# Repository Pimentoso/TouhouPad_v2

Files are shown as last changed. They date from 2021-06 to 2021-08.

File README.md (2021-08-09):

WARNING: THIS REPO IS STILL A WORK IN PROGRESS

Ergonomic gamepad to play Touhou Project games. Left-hand controls shoot/slow/bomb, and right hand controls movement. The bomb button is supposed to be pressed with the left thumb.

This is a newer version which uses a proper circuit board; for the old hand-wired version check here -> https://github.com/Pimentoso/TouhouPad

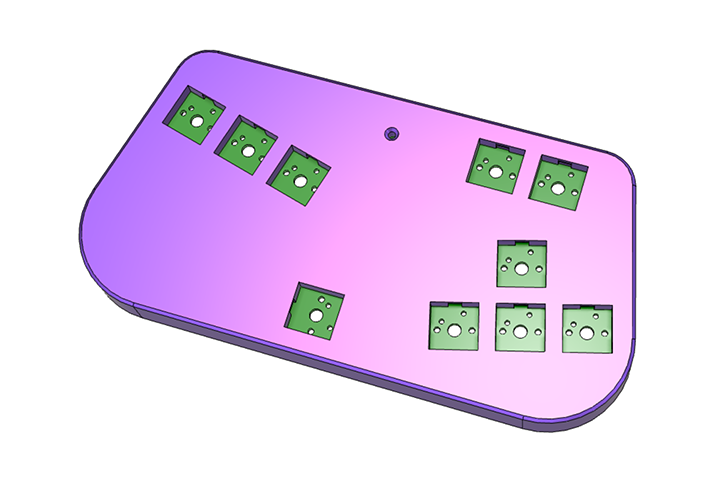
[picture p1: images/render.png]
Rendering


## Ordering the circuit board

- Go to https://jlcpcb.com/
- Create an account if needed.
- Click "order now"
- Upload the file `Archive.zip` you can find in the `kicad/gerber/` directory.
- Leave everything at default (you can change the pcb color if yolu want) and place the order. Note the minimum quantity you can order is 5

## Printing the enclosure

- You will need to 3d print the enclosure for the pad. You can find it in the `stl/` directory
- Print it face down without supports.
- In the top center of the plate there is a small hole. After you finish building the pad, you can stick a very small piece of transparent filament inside the hole to make the arduino power light shine through better.

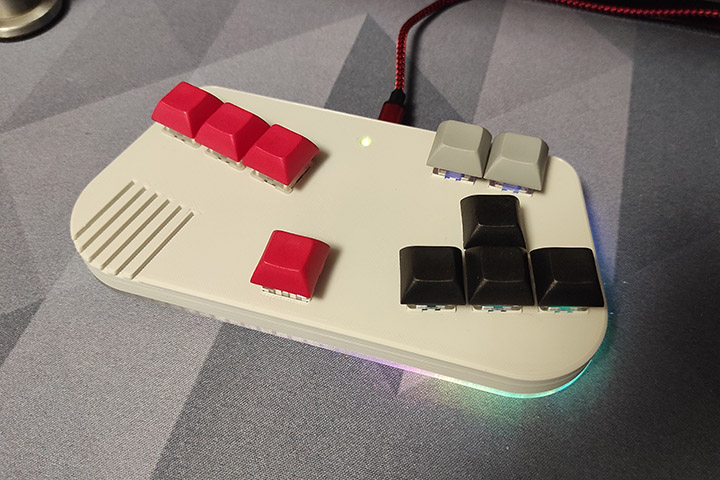
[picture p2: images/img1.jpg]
Top


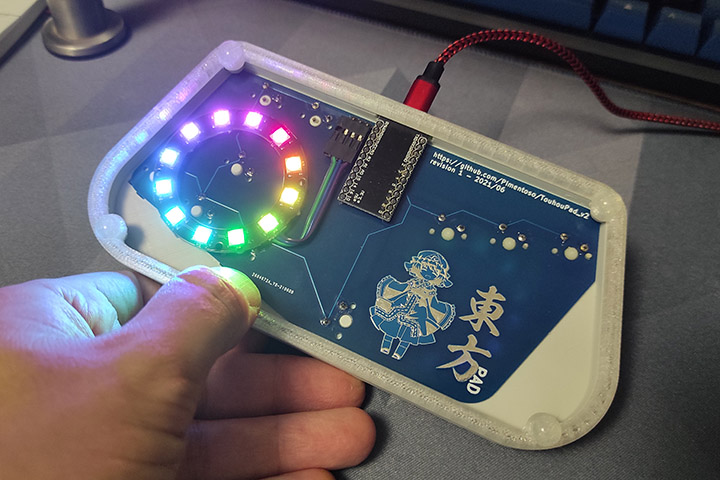
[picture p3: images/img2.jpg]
Bottom


(the circuit board in the picture is the prototype version)

## Building the pad

You will need
- Touhoupad circuit board (see above)
- 3d-printed enclosure
- Arduino pro micro board -> https://www.aliexpress.com/item/32888212119.html (the black one)
- 10x mx-style switches -> https://www.aliexpress.com/item/32899833333.html (gateron red or yellow are good for gaming)
- 10x keycaps -> https://www.aliexpress.com/item/32842379355.html (or just scavenge from an old mechanical keyboard)
- (optional) 4 silicone adhesive dots/feet
- (optional) a short RGB strip (ws2812b LEDs)

Solder the arduino to the circuit board. Place the circuit board inside the case, snap the switches in and solder them.

For RGB underglow: you can use the 3 exposed pins on the circuit board to solder a RGB strip. You can control the RGB lighting as follows

- Press esc+left arrow: toggle lighting on/off
- Press esc+right arrow: cycle lighting effects
- Press esc+up/down arrow: raise/lower brightness

Works better if you print the bottom part of the enclosure with transparent filament. Just pause the print at the 11mm mark and switch the filament to transparent.

## Flashing the firmware

- Method 1: flash `firmware/pimentoso_touhoupad_default.hex` using QMK Toolbox.
- Method 2: flash it directly using qmk firmware: `make pimentoso/touhoupad:default:flash`
- To enter bootloader mode: the bottom of the pad is completely exposed so you have access to the Arduino Pro micro. Just short together the RST and GND pins using a metal object to access bootloader mode.

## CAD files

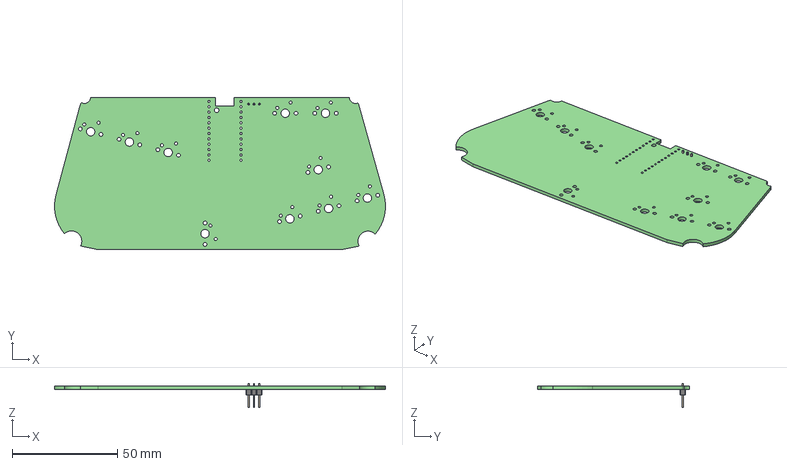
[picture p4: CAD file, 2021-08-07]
step/pcb.step
157.1 x 72.2 x 11.5 mm

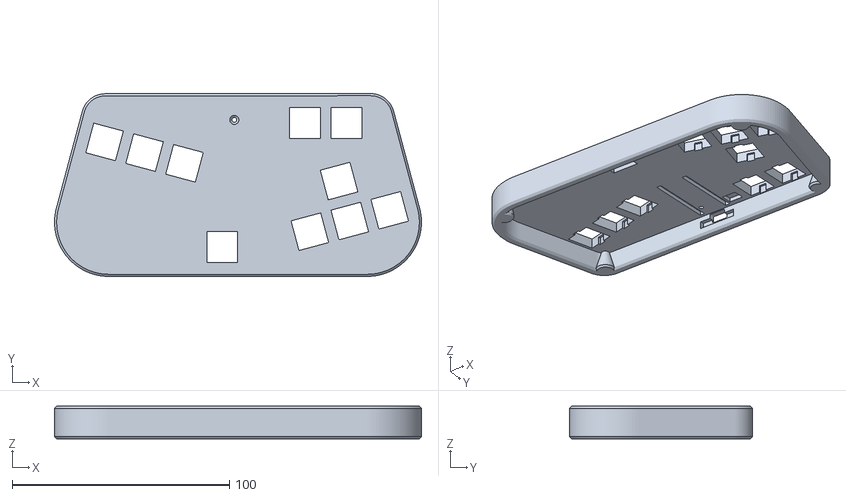
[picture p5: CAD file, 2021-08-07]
stl/touhoupad.stl
169.1 x 84.2 x 15.0

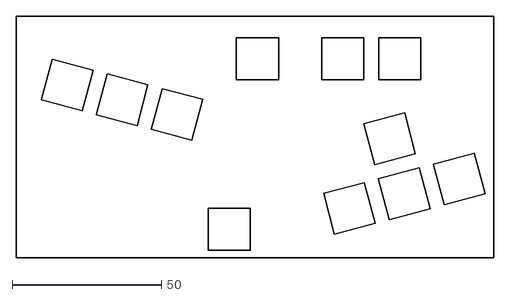
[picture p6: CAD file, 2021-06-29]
dxf/d0646518d6474f0d7bef433ed9ec5677a3568018_switch.dxf
160.0 x 80.8

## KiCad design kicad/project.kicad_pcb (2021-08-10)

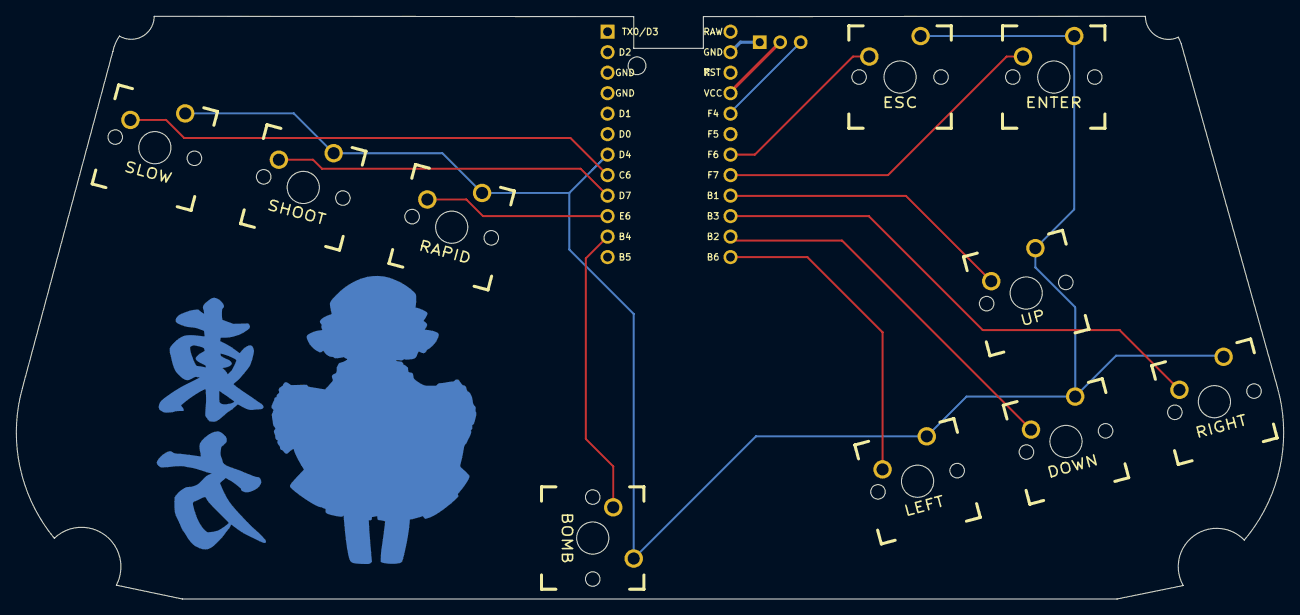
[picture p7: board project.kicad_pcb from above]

Board: 2 copper layers, 157.1 x 72.2 mm, 12 parts (1 on the bottom side), 14 nets.

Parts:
BOMB: SW_DIP_x01; MX_PCB_100H
DOWN: SW_DIP_x01; MX_PCB_100H
ENTER: SW_DIP_x01; MX_PCB_100H
ESC: SW_DIP_x01; MX_PCB_100H
J0: Conn_01x03_Female; PinHeader_1x03_P2.54mm_Vertical
LEFT: SW_DIP_x01; MX_PCB_100H
RAPID: SW_DIP_x01; MX_PCB_100H
RIGHT: SW_DIP_x01; MX_PCB_100H
SHOOT: SW_DIP_x01; MX_PCB_100H
SLOW: SW_DIP_x01; MX_PCB_100H
U0: ProMicro here!; ArduinoProMicro
UP: SW_DIP_x01; MX_PCB_100H

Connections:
unnamed: J0.1, U0.23
unnamed: J0.2, U0.21
unnamed: J0.3, U0.20
unnamed: BOMB.1, DOWN.1, ENTER.1, ESC.1, LEFT.1, RAPID.1, RIGHT.1, SHOOT.1, SLOW.1, U0.7, UP.1
unnamed: SLOW.2, U0.8
unnamed: SHOOT.2, U0.9
unnamed: RAPID.2, U0.10
unnamed: BOMB.2, U0.11
unnamed: ESC.2, U0.18
unnamed: ENTER.2, U0.17
unnamed: LEFT.2, U0.13
unnamed: U0.16, UP.2
unnamed: DOWN.2, U0.14
unnamed: RIGHT.2, U0.15

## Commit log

2021-08-07 3d files
    [pcb.step, project.kicad_pcb, project.step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]
2021-08-10 fix gerbers
    [project-B_Cu.gbr, project-B_Mask.gbr, project-B_Paste.gbr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]
